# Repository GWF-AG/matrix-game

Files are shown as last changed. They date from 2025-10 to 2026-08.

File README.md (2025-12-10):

# Matrix-Game

Copyright (C) 2025 GWF AG, Obergrundstrasse 119, 6002 Lucerne, Switzerland

Contact: info@gwf.ch

## Trial Apprenticeship

This PCB is used as part of the trial apprenticeship for electronics/firmware at GWF AG in Lucerne.

_Deutsch: Schnupperlehre Elektroniker/in EFZ_

## Project

The project is used to practice soldering, measuring and potentially some coding.



The firmware currently supports the following games:
- [x] Snake
- [x] Tic-Tac-Toe
- [x] Drawing
- [x] Bomb Dodging
- [ ] Breakout

Feel free to submit a Pull Request to add more games! :tada:

## Changelogs

The changelogs can be find in the corresponding subdirectories:
- [Firmware Changelog](firmware/CHANGELOG.md)
- [Hardware Changelog](hardware/CHANGELOG.md)

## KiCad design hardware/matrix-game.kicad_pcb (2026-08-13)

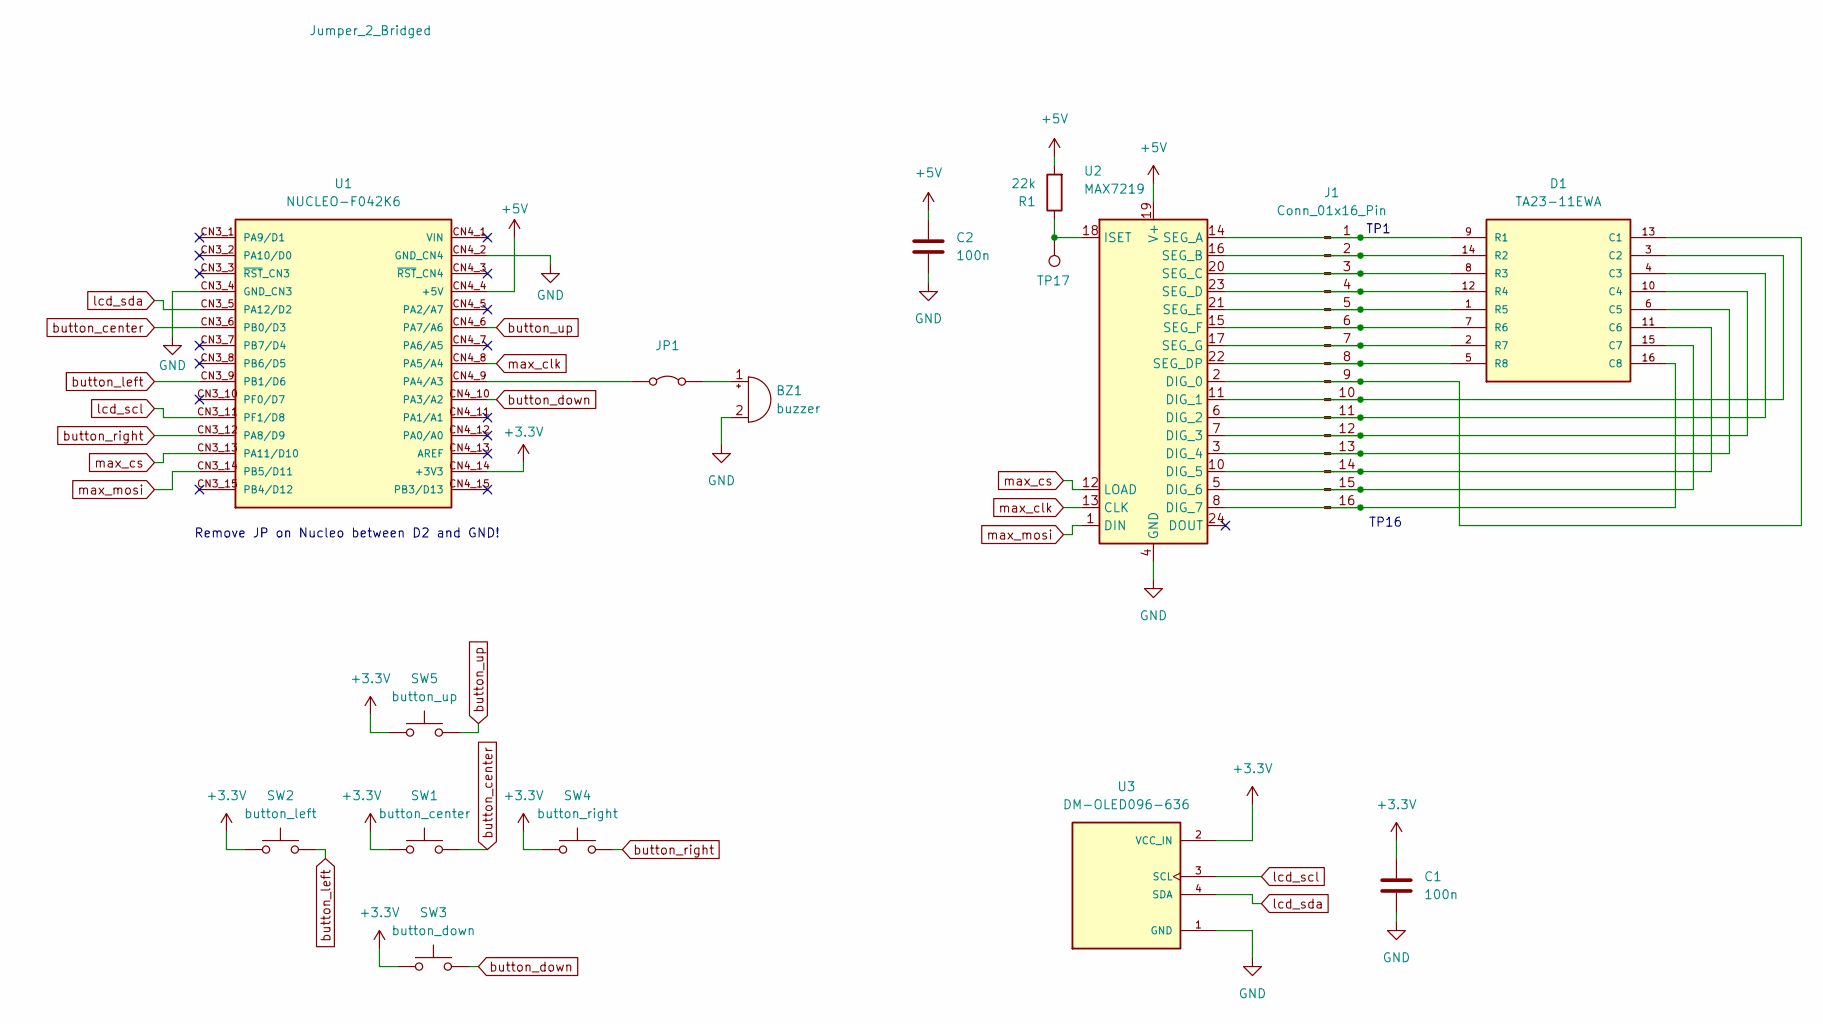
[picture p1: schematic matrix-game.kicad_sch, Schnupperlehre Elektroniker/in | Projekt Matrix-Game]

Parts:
BZ1: buzzer; Buzzer_12x9.5RM7.6
C1, C2: 100n; C_Disc_D3.0mm_W2.0mm_P2.50mm
D1: TA23-11EWA; LED_TA23-11EWA; PARTREV V.10A
J1: Conn_01x16_Pin; PinHeader_1x16_P2.54mm_Vertical
JP1: Jumper_2_Bridged; PinHeader_1x02_P2.54mm_Vertical
R1: 22k; R_Axial_DIN0207_L6.3mm_D2.5mm_P10.16mm_Horizontal
SW1: button_center; SW_PUSH_6mm
SW2: button_left; SW_PUSH_6mm
SW3: button_down; SW_PUSH_6mm
SW4: button_right; SW_PUSH_6mm
SW5: button_up; SW_PUSH_6mm
TP17: TestPoint; PinHeader_1x01_P2.54mm_Vertical
U1: NUCLEO-F042K6; MODULE_NUCLEO-F042K6; PARTREV 8
U2: MAX7219; DIP-24_W7.62mm_Socket
U3: DM-OLED096-636; MODULE_DM-OLED096-636; PARTREV 2018-09-10

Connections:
+3.3V: C1.1, SW1.1, SW2.1, SW3.1, SW4.1, SW5.1, U1.CN4_14 (+3V3), U3.2 (VCC_IN)
+5V: C2.1, R1.2, U1.CN4_4 (+5V), U2.19 (V+)
GND: BZ1.2 (-), C1.2, C2.2, U1.CN3_4 (GND_CN3), U1.CN4_2 (GND_CN4), U2.4 (GND), U2.9 (GND), U3.1 (GND)
unnamed: BZ1.1 (+), JP1.2 (B)
unnamed: D1.13 (C1), J1.9, U2.2 (DIG_0)
unnamed: D1.3 (C2), J1.10, U2.11 (DIG_1)
unnamed: D1.4 (C3), J1.11, U2.6 (DIG_2)
unnamed: D1.10 (C4), J1.12, U2.7 (DIG_3)
unnamed: D1.6 (C5), J1.13, U2.3 (DIG_4)
unnamed: D1.11 (C6), J1.14, U2.10 (DIG_5)
unnamed: D1.15 (C7), J1.15, U2.5 (DIG_6)
unnamed: D1.16 (C8), J1.16, U2.8 (DIG_7)
unnamed: D1.9 (R1), J1.1, U2.14 (SEG_A)
unnamed: D1.14 (R2), J1.2, U2.16 (SEG_B)
unnamed: D1.8 (R3), J1.3, U2.20 (SEG_C)
unnamed: D1.12 (R4), J1.4, U2.23 (SEG_D)
unnamed: D1.1 (R5), J1.5, U2.21 (SEG_E)
unnamed: D1.7 (R6), J1.6, U2.15 (SEG_F)
unnamed: D1.2 (R7), J1.7, U2.17 (SEG_G)
unnamed: D1.5 (R8), J1.8, U2.22 (SEG_DP)
unnamed: JP1.1 (A), U1.CN4_9 (PA4/A3)
unnamed: R1.1, TP17.1, U2.18 (ISET)
button_center: SW1.2, U1.CN3_6 (PB0/D3)
button_down: SW3.2, U1.CN4_10 (PA3/A2)
button_left: SW2.2, U1.CN3_9 (PB1/D6)
button_right: SW4.2, U1.CN3_12 (PA8/D9)
button_up: SW5.2, U1.CN4_6 (PA7/A6)
lcd_scl: U1.CN3_11 (PF1/D8), U3.3 (SCL)
lcd_sda: U1.CN3_5 (PA12/D2), U3.4 (SDA)
max_clk: U1.CN4_8 (PA5/A4), U2.13 (CLK)
max_cs: U1.CN3_13 (PA11/D10), U2.12 (LOAD)
max_mosi: U1.CN3_14 (PB5/D11), U2.1 (DIN)

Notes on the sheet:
TP16
TP1
Remove JP on Nucleo between D2 and GND!

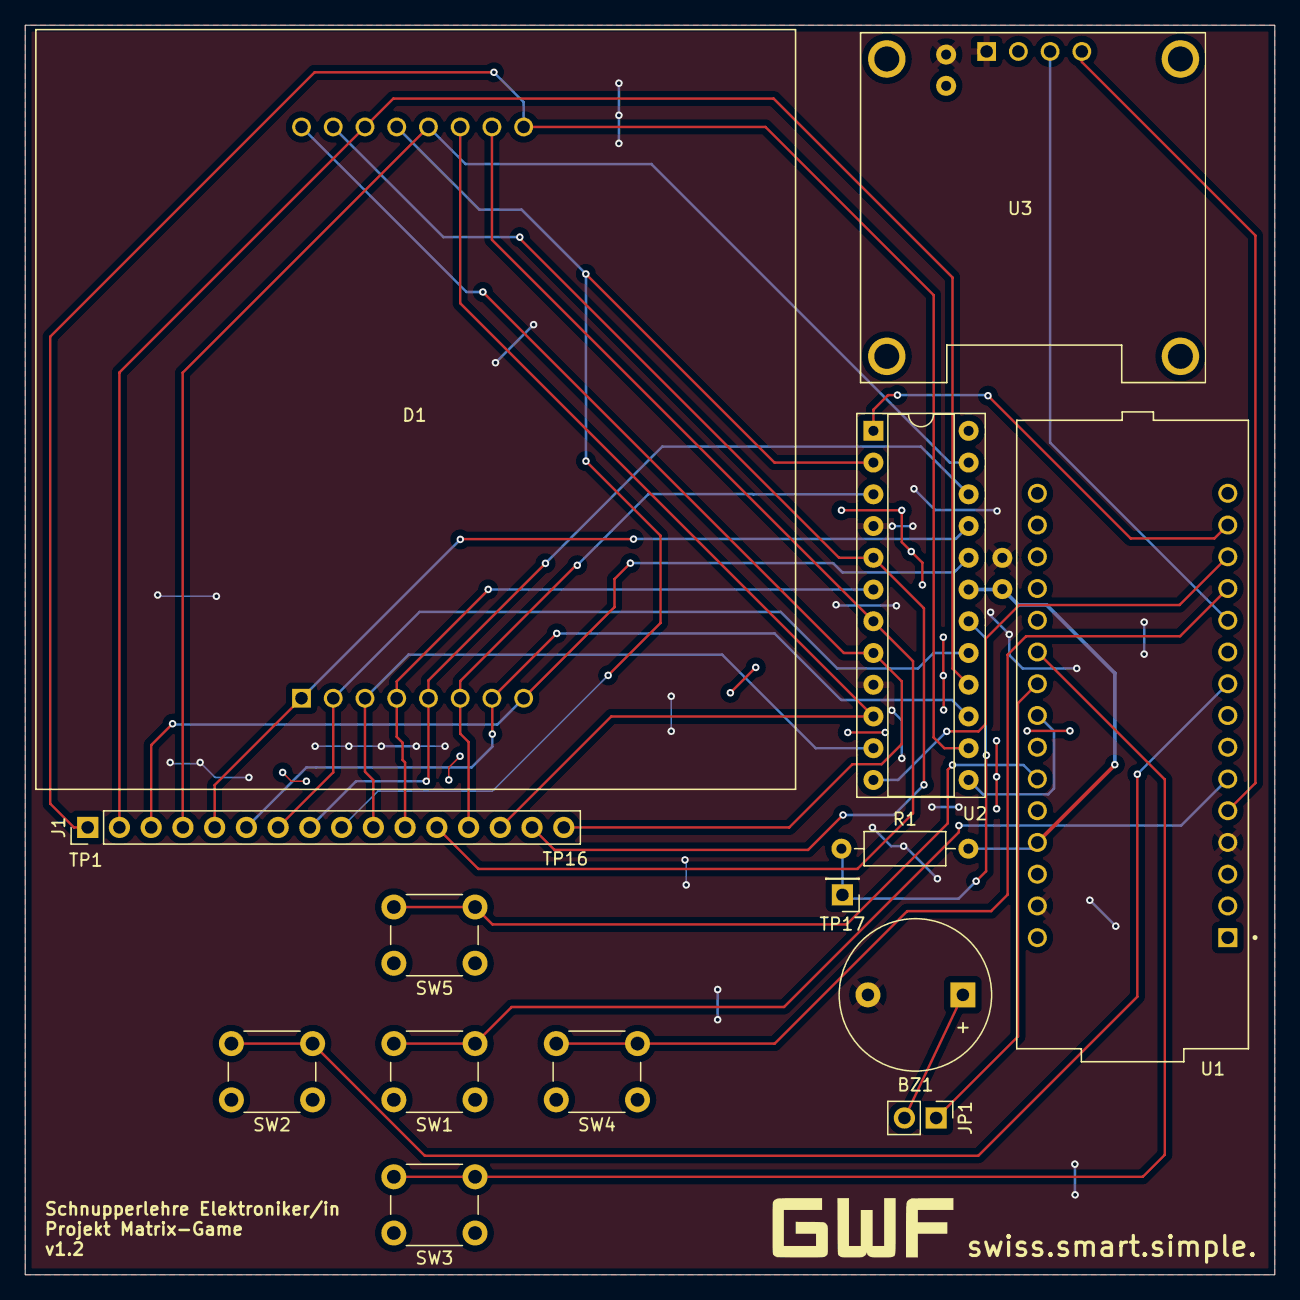
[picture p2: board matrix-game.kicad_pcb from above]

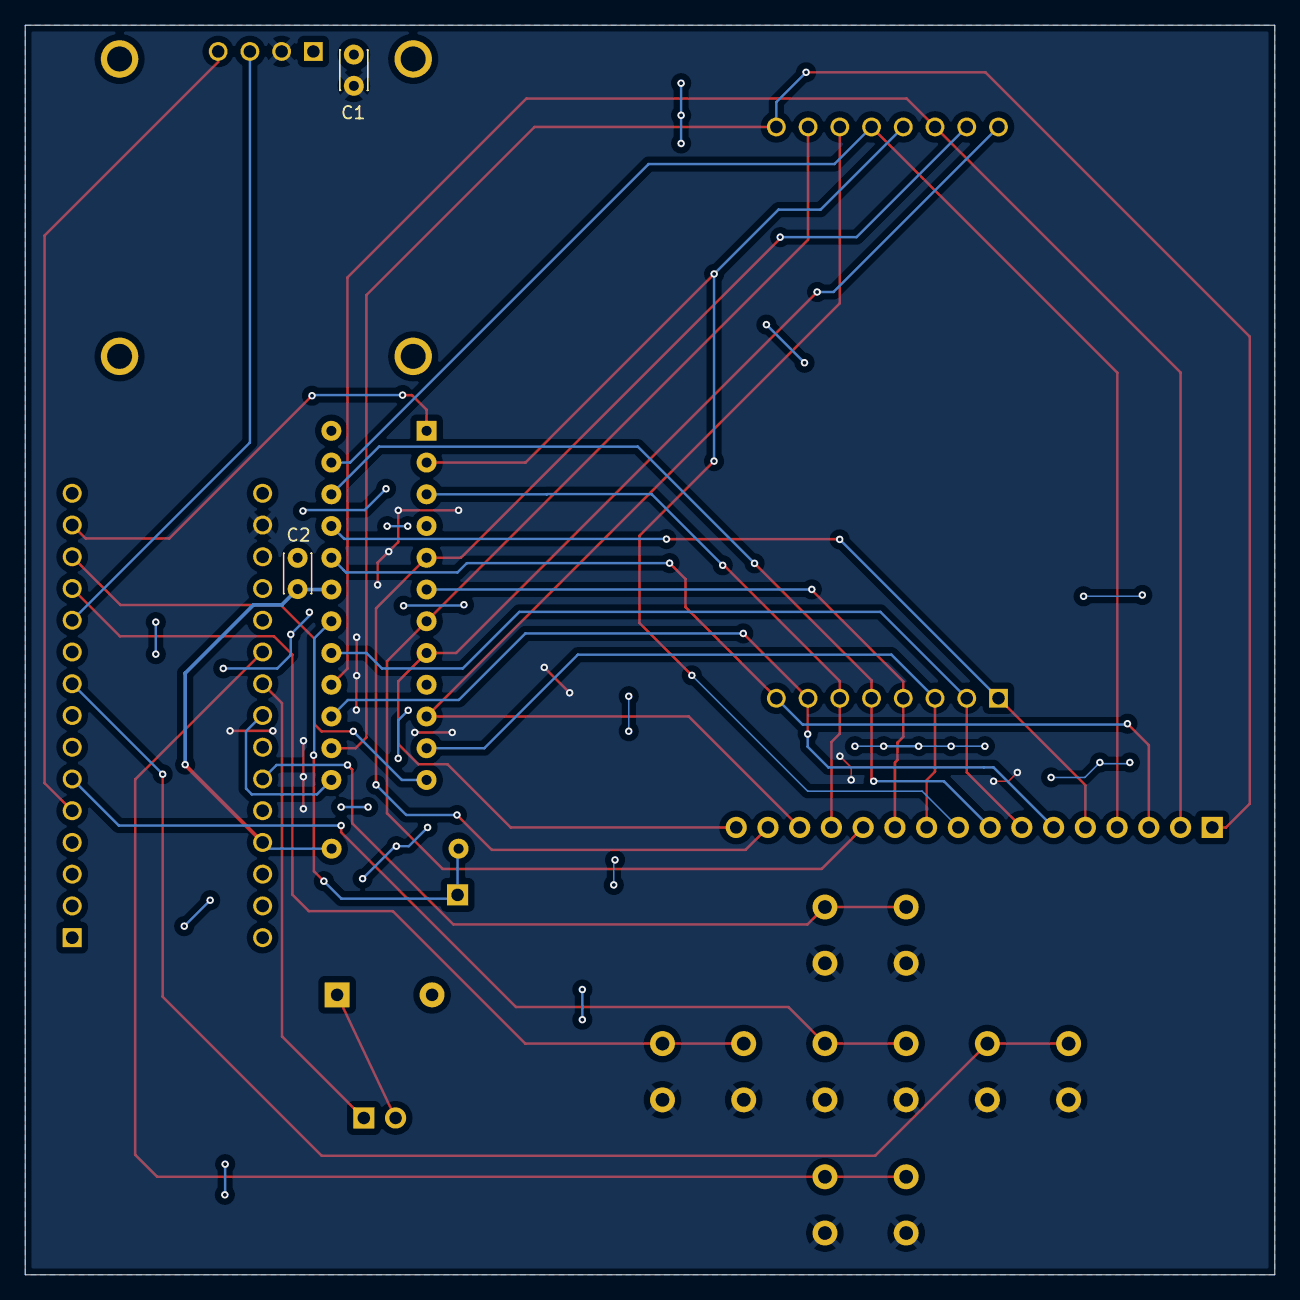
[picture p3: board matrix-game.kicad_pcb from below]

Board: 2 copper layers, 100.0 x 100.0 mm, 16 parts (2 on the bottom side), 32 nets.

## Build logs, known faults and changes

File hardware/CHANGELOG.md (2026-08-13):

# Matrix-Game Hardware Changelog

## [v1.2] -- 2026-08-12
============================

### Fixed:
    - [schematic] Replaced old pin headers with new 1x16, 2.54mm pin headers
    - [layout]    Replaced old pin headers with new 1x16, 2.54mm pin headers

## [v1.1] -- 2025-02-24
============================

### Added:
    - [schematic] added text to remove JP on Nucleo between D2 and GND

### Fixed:
    - [schematic] changed value of R1: 10 kOhm --> 22 kOhm
    - [schematic] wrong connection of R1: GND --> +5V
    - [layout]    wrong connection of R1: GND --> +5V
    - [layout]    adjusted LCD footprint mounting hole distances: 22x22 mm --> 23.5x23.8 mm

## [v1.0] -- 2025-02-07
============================

Initial version

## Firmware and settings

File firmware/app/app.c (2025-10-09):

/**
 * @file app.c
 * @author Timon Burkard (timon.burkard@gwf.ch)
 *
 * @copyright Copyright (c) 2025 GWF AG
 *
 */

#include "app.h"

#include <stdbool.h>
#include <stdlib.h>
#include <stdio.h>

#include "main.h"
#include "max7219.h"
#include "tictactoe.h"
#include "snake.h"
#include "drawing.h"
#include "bombdodging.h"
#include "breakout.h"
#include "ssd1306.h"

#define BUTTON_DEBOUNCE_DELAY_MS 10

#define GAME_OPTIONS_PER_SCREEN 3

extern SPI_HandleTypeDef hspi1;

typedef enum {
    SNAKE       = 0,
    TICTACTOE   = 1,
    DRAWING     = 2,
	BOMBDODGING = 3,
	BREAKOUT	= 4,
    GAME_AMOUNT, // Keep at end!
} game_id_t;

typedef struct {
    game_id_t   id;
    const char* name;
    void (*run)(void);
} game_t;

/* clang-format off */

static game_t games[] = {
    [SNAKE]       = { .id = SNAKE,       .name = "Snake",       .run = snake       },
    [TICTACTOE]   = { .id = TICTACTOE,   .name = "TicTacToe",   .run = tictactoe   },
	[DRAWING] 	  = { .id = DRAWING,     .name = "Drawing",     .run = drawing     },
	[BOMBDODGING] = { .id = BOMBDODGING, .name = "BombDodging", .run = bombdodging },
	[BREAKOUT] 	  = { .id = BREAKOUT,    .name = "Breakout",    .run = breakout    },
};

/* clang-format on */

bool      matrix[MAX7219_COLUMN_AMOUNT][MAX7219_ROW_AMOUNT] = { false };
max7219_t max7219                                           = { 0 };

void app_matrix_clean(bool matrix[MAX7219_COLUMN_AMOUNT][MAX7219_ROW_AMOUNT])
{
    for (uint8_t i = 0; i < MAX7219_COLUMN_AMOUNT; i++) {
        for (uint8_t j = 0; j < MAX7219_ROW_AMOUNT; j++) {
            matrix[i][j] = false;
        }
    }
}

button_t app_get_user_input(void)
{
    static bool button_up_previous     = 0;
    static bool button_down_previous   = 0;
    static bool button_left_previous   = 0;
    static bool button_right_previous  = 0;
    static bool button_center_previous = 0;

    button_t button = BUTTON_NONE;

    bool button_up_current     = HAL_GPIO_ReadPin(BUTTON_UP_GPIO_Port, BUTTON_UP_Pin);
    bool button_down_current   = HAL_GPIO_ReadPin(BUTTON_DOWN_GPIO_Port, BUTTON_DOWN_Pin);
    bool button_left_current   = HAL_GPIO_ReadPin(BUTTON_LEFT_GPIO_Port, BUTTON_LEFT_Pin);
    bool button_right_current  = HAL_GPIO_ReadPin(BUTTON_RIGHT_GPIO_Port, BUTTON_RIGHT_Pin);
    bool button_center_current = HAL_GPIO_ReadPin(BUTTON_CENTER_GPIO_Port, BUTTON_CENTER_Pin);

    if (button_up_current && !button_up_previous) {
        button = BUTTON_UP;
    }

    if (button_down_current && !button_down_previous) {
        button = BUTTON_DOWN;
    }

    if (button_left_current && !button_left_previous) {
        button = BUTTON_LEFT;
    }

    if (button_right_current && !button_right_previous) {
        button = BUTTON_RIGHT;
    }

    if (button_center_current && !button_center_previous) {
        button = BUTTON_CENTER;
    }

    button_up_previous     = button_up_current;
    button_down_previous   = button_down_current;
    button_left_previous   = button_left_current;
    button_right_previous  = button_right_current;
    button_center_previous = button_center_current;

    HAL_Delay(BUTTON_DEBOUNCE_DELAY_MS);

    return button;
}

void app_beep(uint16_t duration_ms)
{
    HAL_GPIO_WritePin(BUZZER_GPIO_Port, BUZZER_Pin, GPIO_PIN_SET);
    HAL_Delay(duration_ms);
    HAL_GPIO_WritePin(BUZZER_GPIO_Port, BUZZER_Pin, GPIO_PIN_RESET);
}

void app_lcd_print_title(void)
{
    SSD1306_Clear();
    SSD1306_GotoXY(0, APP_LCD_ROW_TITLE);
    SSD1306_Puts(APP_LCD_TITLE, &Font_7x10, 1);
    SSD1306_GotoXY(0, APP_LCD_ROW_TITLE_SEPARATION);
    SSD1306_Puts(APP_LCD_TITLE_SEPARATION, &Font_7x10, 1);
    SSD1306_UpdateScreen();
}

static void lcd_print_game_selection(game_id_t game_id)
{
    // Clear all game options
    SSD1306_GotoXY(0, APP_LCD_ROW_GAME_NAME);
    SSD1306_Puts(APP_LCD_EMPTY_LINE, &Font_7x10, 1);
    SSD1306_GotoXY(0, APP_LCD_ROW_GAME_DYNAMIC_0);
    SSD1306_Puts(APP_LCD_EMPTY_LINE, &Font_7x10, 1);
    SSD1306_GotoXY(0, APP_LCD_ROW_GAME_DYNAMIC_1);
    SSD1306_Puts(APP_LCD_EMPTY_LINE, &Font_7x10, 1);

    game_id_t        start_id          = 0;
    static game_id_t start_id_previous = 0;

    // Check if currently selected game is still displayable with the previous start ID
    if ((start_id_previous <= game_id) && (game_id < (start_id_previous + GAME_OPTIONS_PER_SCREEN))) {
        start_id = start_id_previous;
    } else if (game_id < start_id_previous) {
        start_id = game_id;
    } else if (game_id >= (start_id_previous + GAME_OPTIONS_PER_SCREEN)) {
        start_id = game_id - (GAME_OPTIONS_PER_SCREEN - 1);
    }

    for (uint8_t i = 0; i < GAME_OPTIONS_PER_SCREEN; i++) {
        if ((start_id + i) >= GAME_AMOUNT) {
            break;
        }

        if ((start_id + i) == game_id) {
            SSD1306_GotoXY(0, APP_LCD_ROW_GAME_NAME + (i * APP_LCD_ROW_GAME_DIFFERENCE));
            SSD1306_Puts(">", &Font_7x10, 1);
        }

        SSD1306_GotoXY(APP_LCD_COL_GAME_SELECTION_INDENTATION, APP_LCD_ROW_GAME_NAME + (i * APP_LCD_ROW_GAME_DIFFERENCE));
        SSD1306_Puts(games[start_id + i].name, &Font_7x10, 1);
    }

    SSD1306_UpdateScreen();

    start_id_previous = start_id;
}

static game_id_t select_game(void)
{
    button_t         button  = BUTTON_NONE;
    static game_id_t game_id = SNAKE;

    app_lcd_print_title();

    lcd_print_game_selection(game_id);

    do {
        do {
            button = app_get_user_input();
        } while (button == BUTTON_NONE);

        if (button == BUTTON_DOWN) {
            if (game_id < (GAME_AMOUNT - 1)) {
                ++game_id;
            }

            lcd_print_game_selection(game_id);
        }

        if (button == BUTTON_UP) {
            if (game_id > 0) {
                --game_id;
            }

            lcd_print_game_selection(game_id);
        }
    } while (button != BUTTON_CENTER);

    return game_id;
}

void app(void)
{
    game_id_t game_id;

    if (max7219_init(&max7219, &hspi1, MAX_SPI_CS_GPIO_Port, MAX_SPI_CS_Pin) != MAX7219_OK) {
        for (;;) {
        } // Error handling...
    }

    SSD1306_Init();

    for (;;) {
        app_matrix_clean(matrix);

        if (max7219_set_matrix(&max7219, matrix) != MAX7219_OK) {
            for (;;) {
            } // Error handling...
        }

        game_id = select_game();

        if (games[game_id].run != NULL) {
            games[game_id].run();
        }
    }
}

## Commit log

2025-10-09 [firmware] BombDodger refactoring: switched row to col
2025-10-09 [firmware] BombDodger enable user to exit the game by pressing CENTER button
2026-08-13 [hardware] Replaced old TP pins with a 1x16, 2.54mm pin header
    [matrix-game.kicad_pcb, matrix-game.kicad_sch]
2026-08-13 [hardware/doc] updated changelog
    [matrix-game.kicad_pcb, matrix-game.kicad_sch]
